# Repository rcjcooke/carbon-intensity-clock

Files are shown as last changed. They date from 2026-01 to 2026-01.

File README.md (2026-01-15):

# carbon-intensity-clock
A clock that shows when the next forecast window is for the greenest energy in the UK.

# Usage

The clock will automatically determine the current UK time (adjusted for Daylight Savings as appropriate). This will be shown in blue. From that point onwards, the next full rotation of 12 hours will show in varying shades of green or red when it is best to use electricity in your location based on what the forecast carbon usage at that time will be. i.e. If it's more green, there's more renewable energy on the grid. If it's more red, there's a higher proportion of fossil fuels being burnt to supply the grid. Each block on the clock is a 30 minute segment. Set your dishwasher / washing machine / other delayable electricty using process to start and finish in as green a window as you can!

# File Structure

Important files listed here

```
electronics/datasheets - For all relevant datasheets
electronics/Schematic.fzz - Fritzing electronic schematic
hardware/Carbon Intensity Clock v1.f3z - Fusion 360 model
software - Platform I/O project
media - Media used in the README.md
```

# Requirements

The following raw materials, components and tools are required to build this.

## Bill of Materials
- For 3D printing:
  - PLA filament (white)
- For laser cutting:
  - 0.5mm thick transparent acrylic sheet ~ 80x80mm
  - 0.5mm thick translucent acrylic sheet ~ 80x80mm
    - Or use more transparent and a "frosting spray" to make it translucent
  - 0.5mm thick opaque white ABS sheet ~ 80x80mm
- 3mm domed screws, 6mm long (head is assumed to be 5mm diameter or less, and 2mm high or less) x4
- [2.1mm jack power socket](https://uk.farnell.com/wurth-elektronik/694108301002/connector-power-entry-jack-3a/dp/2472153)
- [Arduino Nano ESP32 Board](https://uk.rs-online.com/web/p/arduino/2686963)
- [5V 3A Buck Convertor](https://thepihut.com/products/ubec-dc-dc-step-down-buck-converter-5v-3a-output?variant=27739329617)
- [74AHCT125 - Quad Level-Shifter (3V to 5V)](https://thepihut.com/products/74ahct125-quad-level-shifter-3v-to-5v?variant=27739617873)
- Some 22 AWG (minimum) cable to connect everything together
- A 2.1mm jacked DC power source able to supply at least 9W at between 6 and 21V with the positive voltage supplied on the pin. 

## Required Tools
- 3D Printer (At least 80x80x22mm build volume)
- Laser Cutter (Powerful enough to cut 0.5mm thick ABS + Acrylic) - if you don't have access to one, then there are various online laser cutting services that you could send the files to to have them cut for you.
- Soldering Iron + accessories
- PZ2 screwdriver
- Plastic solvent, e.g. Tensol 12 for sticking the acrylics and ABS together

# Build Instructions

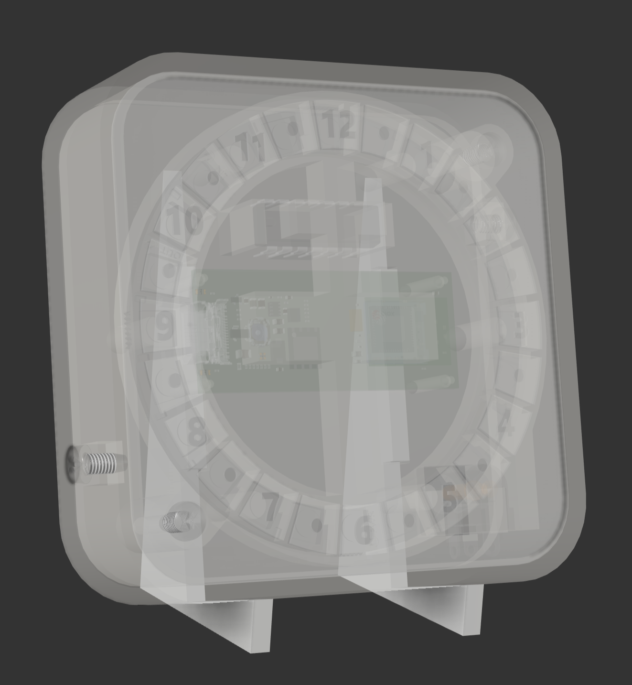
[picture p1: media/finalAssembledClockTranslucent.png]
Final Assembled Clock Translucent


It's _much_ easier to do the software build and upload _before_ the Nano is integrated in to the clock, so I strongly recommend following the Software instructions first, before doing any assembly.

## Software
- Note: This project was created on VS Code using Platform I/O so easiest to load it up in that. You could build it in the Arduino IDE but you'd need to tweak it and get the appropriate libraries.
- Rename `exampleWifiCredentials.h` to `wifiCredentials.h` and populate it with your WiFi network name and password.
- In `main.cpp` update the `POST_CODE` constant to the start of your post code (since the grid's electricity supply is different in different parts of the country).
- Build and upload to the Arduino Nano ESP32.

## Hardware
### Manufacture
- 3D Print the following in white PLA (or whatever you want to print it in frankly!). NOTE: This is has been designed so that all components can be printed with no supports and no post-print cleanup required.
  1. Thing
  2. Thing 2
- Create the face plate:
  - Laser cut the following
    1. Thing
  - If you're not cutting translucent acrylic then frost spray the top of all of the pieces cut from number 1 now.
  - Glue the largest piece of 3 to 2 (the face base)
  - Glue all of the translucent pieces (1) in the correct slots
  - Fill in the holes by gluing in the remaining pieces from 3

### Electronics

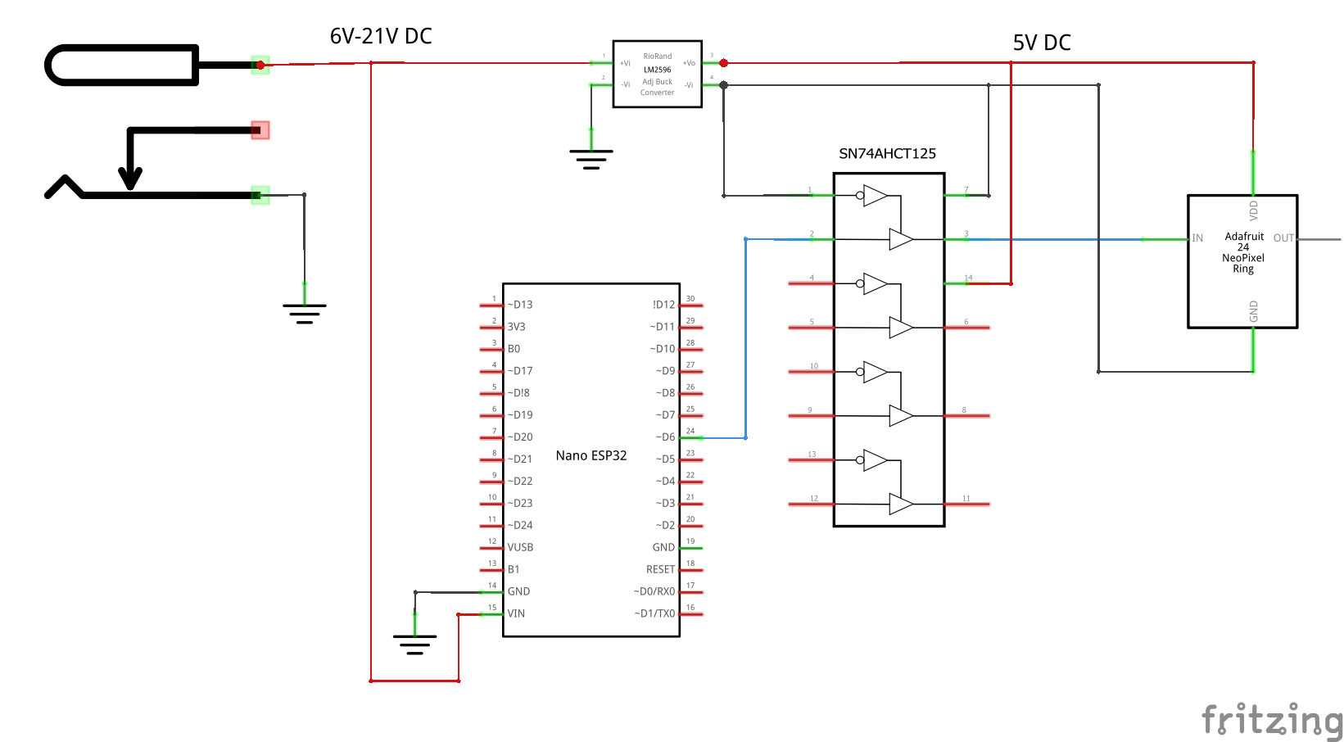
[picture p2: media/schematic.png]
Electronics schematic


- Connect up all the electronic components (ignore the part label for the buck convertor on the schematic above - I couldn't find that specific buck convertor on Fritzing)
  - 

### Assembly

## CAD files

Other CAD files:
hardware/Carbon Intensity Clock v1.f3z

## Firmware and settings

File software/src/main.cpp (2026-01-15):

/*
NOTE: To use this:
 - Rename "exampleWifiCredentials.h" to "wifiCredentials.h" and update the SSID and 
   password to those required for your wifi network.
 - Change POST_CODE to your post code
 - Change GMT_OFFSET_SEC and DAYLIGHT_OFFSET_SEC to values for your location
 - Update LED_PIN to the pin you have connected the LED ring to 
*/
#include <Arduino.h>
#include <WiFi.h>
#include <HTTPClient.h>
#include <time.h>
#include <ArduinoJson.h>
#include <limits.h>
#include <map>
#include <Adafruit_NeoPixel.h>

// Wifi credentials recorded in this file
#include "wifiCredentials.h"

/************************
 * Pins
 ************************/
#define LED_PIN     6 // Pin where the LED ring is connected

/************************
 * Constants
 ************************/
// The characters used for the "waiting" spinner on the display
static const char WAITING_CHARS[] = "-\\|/";
// Post code used for API check
static const String POST_CODE = "KT6";
// The NTP server to sync time from
static const char* NTP_SERVER = "pool.ntp.org";
// The local offset from GMT in seconds
static const long GMT_OFFSET_SEC = 0;

// Datetime in ISO8601 format YYYY-MM-DDThh:mmZ e.g. 2017-08-25T12:35Z
static const char* API_DATE_FORMAT = "%FT%RZ";
// Period between data refreshes - 30 minutes in milliseconds
static const unsigned long REFRESH_PERIOD_MS = 30 * 60 * 1000;

// Number of LEDs in the ring
static const int LED_COUNT = 24;
// Time per LED in seconds
static const int TIME_PER_LED_SEC = (12 * 60 * 60) / LED_COUNT;

// API returned a 400 status code
static const int API_400_ERROR = 1;
// API returned a 500 status code
static const int API_500_ERROR = 2;
// API returned an unknown error
static const int API_UNKNOWN_ERROR = 3;
// Failed to retrieve the current time
static const int TIME_RETRIEVAL_ERROR_1 = 4;
// Failed to retrieve the current time after daylight savings time change
static const int TIME_RETRIEVAL_ERROR_2 = 5;
// Failed to deserialise JSON from the API
static const int JSON_DESERIALISATION_ERROR = 6;

/************************
 * Variables
 ************************/
// The LED Strip
Adafruit_NeoPixel strip(LED_COUNT, LED_PIN, NEO_GRB);
// The Colour scale array
uint32_t colourScale[256];
// The local offset for daylight savings time in seconds
int daylightOffsetSec = 0;

/************************
 * Utility functions
 ************************/
// Format Wi-Fi status to something human readable
String formatWiFiStatus(wl_status_t status) {
  switch (status) {
    case WL_NO_SHIELD:
      return "WL_NO_SHIELD";
    case WL_IDLE_STATUS:
      return "WL_IDLE_STATUS";
    case WL_NO_SSID_AVAIL:
      return "WL_NO_SSID_AVAIL";
    case WL_SCAN_COMPLETED:
      return "WL_SCAN_COMPLETED";
    case WL_CONNECTED:
      return "WL_CONNECTED";
    case WL_CONNECT_FAILED:
      return "WL_CONNECT_FAILED";
    case WL_CONNECTION_LOST:
      return "WL_CONNECTION_LOST";
    case WL_DISCONNECTED:
      return "WL_DISCONNECTED";
    default:
      return "UNKNOWN STATUS: " + status;
  }
}

// Format a time string from a tm struct
String createFormattedTimeString(const tm* time, const char* format) {
  char timeString[100];
  strftime(timeString, 100, format, time);
  return String(timeString);
}

// Populates the colour scale array from green (low) to white (mid) to red (high)
void populateColourScale() {
  for (int i = 0; i < 256; i++) {
    if (i < 128) {
      // Green to White
      uint8_t green = 255;
      uint8_t red = map(i, 0, 127, 0, 255);
      uint8_t blue = map(i, 0, 127, 0, 255);
      colourScale[i] = strip.Color(red, green, blue);
    } else {
      // White to Red
      uint8_t red = 255;
      uint8_t green = map(i, 128, 255, 255, 0);
      uint8_t blue = map(i, 128, 255, 255, 0);
      colourScale[i] = strip.Color(red, green, blue);
    }
  }
}

void connectWiFi() {
  // Connect and let us know how that goes
  wl_status_t status;
  unsigned long prevMillis = millis();
  while (status != WL_CONNECTED) {
    // If the status has changed, let us know
    if (WiFi.status() != status) {
      status = WiFi.status();
      Serial.println();
      Serial.println("WiFi status change to: " + formatWiFiStatus(status));
      Serial.print("Connecting to wiFi");
    }
    // Update the LED ring animation - assume we do 1 loop per 500 ms
    // The animation consists of a circling comet of 3 blue LEDs with the brighest LED at the head
    if (millis() - prevMillis >= 500 / LED_COUNT) {
      static int animationIndex = 0;
      strip.clear();
      for (int i = 0; i < 3; i++) {
        int ledIndex = (animationIndex + i) % LED_COUNT;
        uint8_t brightness = 255 - (i * 80); // Decrease brightness for trailing LEDs
        strip.setPixelColor(ledIndex, strip.Color(0, 0, brightness));
      }
      strip.show();
      animationIndex = (animationIndex + 1) % LED_COUNT;
    }
    
    // If it's been 500 ms since last time we checked, let us know we're still alive on Serial as well
    if (millis() - prevMillis >= 500) {
      Serial.print(".");
      prevMillis = millis();
    }

  }
  Serial.println();
  Serial.println("Connected. IP: " + WiFi.localIP().toString());
}

// Show which error has occured on the LED ring with one LED in yellow indicating the error index and the rest in dim white
void showErrorOnLEDs(int errorIndex) {
  strip.clear();
  for (int i = 0; i < LED_COUNT; i++) {
    if (i == errorIndex % LED_COUNT) {
      strip.setPixelColor(i, strip.Color(255, 255, 0)); // Yellow for error index
    } else {
      strip.setPixelColor(i, strip.Color(50, 50, 50)); // Dim white for others
    }
  }
  strip.show();
}

// Given that this is always in the UK, we can determine the daylight savings time offset based on the date. Returns true if the offset has changed.
boolean setDaylighSavingsTimeOffset(const tm* time) {

  int existingOffset = daylightOffsetSec;

  int month = time->tm_mon + 1; // tm_mon is 0-11
  int day = time->tm_mday;
  int wday = time->tm_wday; // 0 = Sunday
  int hour = time->tm_hour;

  // DST starts last Sunday in March at 1am UTC
  if (month > 3 && month < 10) {
    // Definitely in DST
    daylightOffsetSec = 3600;
  } else if (month < 3 || month > 10) {
    // Definitely not in DST
    daylightOffsetSec = 0;
  } else if (month == 3) {
    // Check if last Sunday
    if ((day + (7 - wday)) > 31) {
      // Last Sunday
      if (hour >= 1) {
        daylightOffsetSec = 3600;
      } else {
        daylightOffsetSec = 0;
      }
    } else {
      daylightOffsetSec = 0;
    }
  } else if (month == 10) {
    // Check if last Sunday
    if ((day + (7 - wday)) > 31) {
      // Last Sunday
      if (hour >= 1) {
        daylightOffsetSec = 0;
      } else {
        daylightOffsetSec = 3600;
      }
    } else {
      daylightOffsetSec = 3600;
    }
  }

  return (existingOffset != daylightOffsetSec);
}

/************************
 * Entry point methods
 ************************/
void setup() {

  // Set up serial interface comms
  Serial.begin(115200);
  while(!Serial); // Wait for initialisation of the serial interface

  // Set up the LED arrays and strip
  populateColourScale();
  strip.begin();
  strip.show(); // Initialize all pixels to 'off'

  // Set up the Wifi connection - credentials pulled from included wifiCredentials.h (git ignored)
  Serial.println("Starting up WiFi interface");
  WiFi.begin(ssid, password);

  // Establish WiFi connection
  connectWiFi();

  // Initialise the time library
  configTime(GMT_OFFSET_SEC, daylightOffsetSec, NTP_SERVER);
  struct tm currentTime;
  if(!getLocalTime(&currentTime)) {
    Serial.println("Failed to obtain time");
  } else {
    Serial.println("Current time: " + createFormattedTimeString(&currentTime, API_DATE_FORMAT));
  }

}

void loop() {

  static unsigned long prevMillis = millis() - REFRESH_PERIOD_MS;

  unsigned long currentMillis = millis();
  if (currentMillis - prevMillis >= REFRESH_PERIOD_MS) {
    prevMillis += REFRESH_PERIOD_MS;

    // If the WiFi connection status has changed, let us know and wait for reconnect
    if (WiFi.status() != WL_CONNECTED) {
      connectWiFi();
    }

    // Get the current time
    struct tm currentTime;
    if(!getLocalTime(&currentTime)) {
      Serial.println("Failed to obtain time");
      showErrorOnLEDs(TIME_RETRIEVAL_ERROR_1);
      return;
    }
    // Determine whether it is daylight savings time and apply it to the current time if it is
    if (setDaylighSavingsTimeOffset(&currentTime)) {
      // Reconfigure time library with new daylight savings offset
      configTime(GMT_OFFSET_SEC, daylightOffsetSec, NTP_SERVER);
      // Re-fetch the current time with the new offset applied
      if(!getLocalTime(&currentTime)) {
        Serial.println("Failed to obtain time");
        showErrorOnLEDs(TIME_RETRIEVAL_ERROR_2);
        return;
      }
    }

    time_t timein12Hours = mktime(&currentTime) + 12 * 60 * 60;

    // Format the current time for the API request
    String nowString = createFormattedTimeString(&currentTime, API_DATE_FORMAT); 
    
    HTTPClient client;
    String apiURL = "https://api.carbonintensity.org.uk/regional/intensity/" + nowString + "/fw24h/postcode/" + POST_CODE;
    client.begin(apiURL);
    int httpCode = client.GET();
    if (httpCode == 200) {

      // Extract the next 12 hours of intensities into a map

      String payload = client.getString();
      JsonDocument jsonDoc;
      DeserializationError error = deserializeJson(jsonDoc, payload);

      if (error) {
        Serial.print("deserializeJson() failed: ");
        Serial.println(error.c_str());
        showErrorOnLEDs(JSON_DESERIALISATION_ERROR);

        return;
      }

      JsonObject data = jsonDoc["data"];

      struct intensityDatum {
        time_t to;
        int intensity;
      };
      std::map<unsigned long, intensityDatum> intensityMap;
      int minIntensity = INT_MAX;
      int maxIntensity = INT_MIN;
      for (JsonObject data_data_item : data["data"].as<JsonArray>()) {

        const char* data_data_item_from = data_data_item["from"]; // "2025-11-29T13:00Z", "2025-11-29T13:30Z", ...
        time_t fromTime = 0;
        struct tm tm_from = {};
        strptime(data_data_item_from, API_DATE_FORMAT, &tm_from);

        // The returned array is ordered, so if we're over the 12 hour window we can stop processing
        fromTime = mktime(&tm_from);
        if (fromTime > timein12Hours) {
          break;
        }

        const char* data_data_item_to = data_data_item["to"]; // "2025-11-29T13:30Z", "2025-11-29T14:00Z", ...
        int data_data_item_intensity_forecast = data_data_item["intensity"]["forecast"]; // 65, 66, 60, 61, 76, ...
        
        // Translate the times to time_t timestamps and store in map
        time_t toTime = 0;
        struct tm tm_to = {};
        strptime(data_data_item_to, API_DATE_FORMAT, &tm_to);
        toTime = mktime(&tm_to);
        intensityMap[fromTime] = {toTime, data_data_item_intensity_forecast};
        
        // Keep track of min and max intensity values so we can define our colour scale later
        if (data_data_item_intensity_forecast < minIntensity) {
          minIntensity = data_data_item_intensity_forecast;
        }
        if (data_data_item_intensity_forecast > maxIntensity) {
          maxIntensity = data_data_item_intensity_forecast;
        }
        
      }

      // Extract the current 12 hour time from the current time object in seconds
      unsigned long currentTime12HourSecs = currentTime.tm_hour % 12 * 3600 + currentTime.tm_min * 60 + currentTime.tm_sec;
      
      // Given the lED ring represents a 12 hour clock, work out which LED index represents the current time
      int currentTimeLEDIndex = map(currentTime12HourSecs, 0, 12 * 3600, 0, LED_COUNT - 1);

      // Paint the current time LED blue
      strip.setPixelColor(currentTimeLEDIndex, strip.Color(0, 0, 255));

      // Use linear interpolation to map intensity values from the half-hourly data to per-led data for the 12 hour period
      time_t currentTimeT = mktime(&currentTime);
      for (int ledIndex = 1; ledIndex < LED_COUNT; ledIndex++) {
        time_t ledTime = currentTimeT + ledIndex * TIME_PER_LED_SEC;
        int intensity = 0;
        // Find the two intensity data points that bracket this time
        auto upper = intensityMap.lower_bound(ledTime);
        if (upper == intensityMap.end()) {
          // Out of range - use the last known value
          intensity = std::prev(upper)->second.intensity;
        } else if (upper == intensityMap.begin()) {
          // Out of range - use the first known value
          intensity = upper->second.intensity;
        } else {
          auto lower = std::prev(upper);
          // Do linear interpolation
          time_t t0 = lower->first;
          time_t t1 = upper->first;
          int i0 = lower->second.intensity;
          int i1 = upper->second.intensity;
          intensity = i0 + (i1 - i0) * (ledTime - t0) / (t1 - t0);
        }
        // Map the intensity to a colour index
        int colourIndex = map(intensity, minIntensity, maxIntensity, 0, 255);
        colourIndex = constrain(colourIndex, 0, 255);
        
        // Set the colour on the LED - starting from the current time LED index
        strip.setPixelColor((currentTimeLEDIndex + ledIndex) % LED_COUNT, colourScale[colourIndex]);
      }
      
      // Show the updated LED ring
      strip.show();
      // Clear off the JSON document to free memory
      jsonDoc.clear();

    } else if (httpCode == 400) {

      // Bad request
      Serial.println("Bad request (400)");
      Serial.println("API time string: " + nowString);
      Serial.println("Post code: " + POST_CODE);
      Serial.println("API request URL: " + apiURL);

      showErrorOnLEDs(API_400_ERROR);

      // Wait until the next refresh period to try again
      // We wouldn't expect the next refresh to work either as the implication is that the API has changed in a backwards incompatible some way

    } else if (httpCode == 500) {

      // Internal Server Error
      Serial.println("Internal Server error (500)");
      
      showErrorOnLEDs(API_500_ERROR);
      
      // Wait until the next refresh period to try again

    } else {

      // Failed for unexpected reason
      Serial.println("Error making API request: " + httpCode);

      showErrorOnLEDs(API_UNKNOWN_ERROR);
      
      // Wait until the next refresh period to try again
      
    }
  }
}

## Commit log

2025-11-30 Added sample download and data analysis
2025-12-01 Fixed time variable overflow problem
    [main.cpp]
2025-12-02 First cut of theoretically fully happy path functioning code
2026-01-15 Added LED indicators for errors and Wifi connecting. Set number of LEDs now we know.
    [main.cpp]
2026-01-15 Made all other errors visible on LEDs. Added error codes. Automated setting DST.
    [main.cpp]
2026-01-15 First cut of readme - TBC
    [Schematic.fzz]
2026-01-15 Bit of a re-org of files and added Fusion 360 archive file.
    [Carbon Intensity Clock v1.f3z, Schematic.fzz]
2026-01-15 Schematic library update
    [Schematic.fzz]
